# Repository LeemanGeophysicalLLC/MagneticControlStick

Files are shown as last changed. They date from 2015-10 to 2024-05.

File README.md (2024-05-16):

# Magnetic Control Stick

**THIS PRODUCT HAS BEEN RETIRED AND IS NO LONGER PRODUCED**

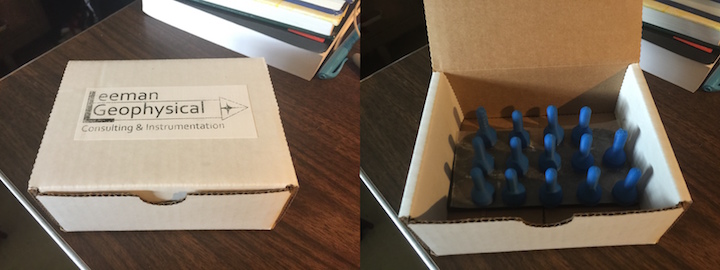
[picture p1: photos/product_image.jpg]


Magnet holder for controlling electronic devices. Designed for the
GeoPebble project at Penn State by John R. Leeman. Current design utilizes
0.5" x 0.125" rare earth magnets.

* We recommend super-glue or equivalent to ensure magnets stay in
the holders in all conditions.
* We have noticed that any extra gap in the space between the
bottom of the stick and the magnet surface can significantly decrease
performance. You can sand away extra plastic material after gluing magnets in
or reduce the gap in the OpenSCAD file.
* Printed on Taz4 by Lulzbot with no raft, skirt, or brim. Medium or fast
speed with ABS plastic. 40% infill.

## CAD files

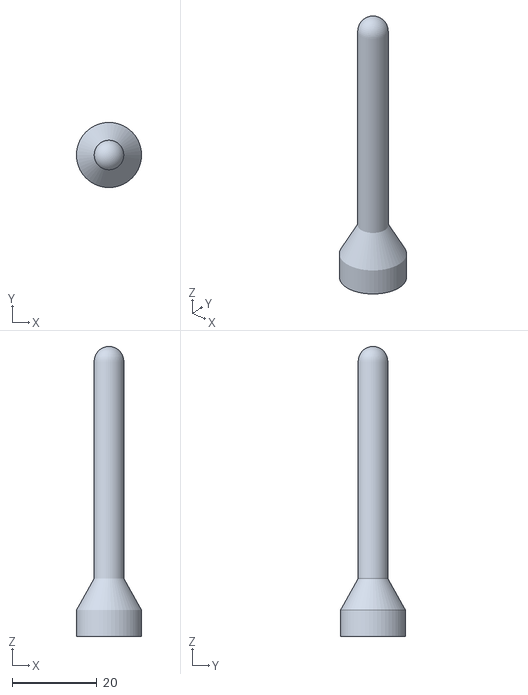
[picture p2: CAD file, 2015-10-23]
stl_files/Magnetic_Control_Stick_Tall.stl
15.4 x 15.4 x 68.5

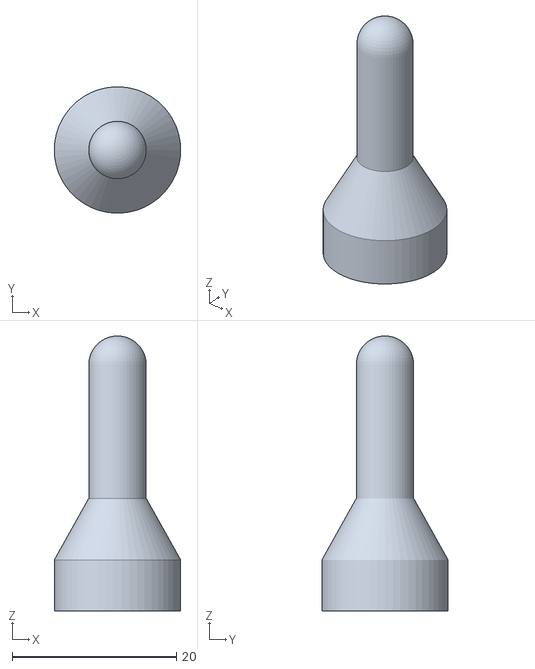
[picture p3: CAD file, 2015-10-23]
stl_files/Magnetic_Control_Stick_Short.stl
15.4 x 15.4 x 33.5

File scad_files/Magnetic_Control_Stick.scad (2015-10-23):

// Resolution
$fn=50;

// Paramters of the stick
stick_diameter = 7; // Handle Diameter (nominal 7 mm)
height = 30; // Total Height (nominal 30 mm or 65 mm)
wall_thickness = 2; // Thickness of sides/top of magnet area (nominal 2 mm)
recess_depth = 1; // Recess depth of magnet in bottom (nominal 0-1 mm)
taper_height = 7.5; // How tall the taper is (nominal 7.5 mm)

// Magnet Holes (actual + fudge factor)
magnet_radius = 6.35 + 0.35;
magnet_depth = 3.175 + 0.05;

// Calculated parameters
stick_radius = stick_diameter/2.;
stick_height = height - magnet_depth - wall_thickness - recess_depth;

base_width = (magnet_radius*2) + wall_thickness;
base_radius = base_width/2.;

union(){

    // Make the base of the stand with holes for the magnet
    difference(){
        // Base
        cylinder(magnet_depth + wall_thickness + recess_depth,base_radius,base_radius);
        // Make hole for magnet
        cylinder(magnet_depth + wall_thickness, magnet_radius,magnet_radius);
    }
 
    // Make the stick and round topper
    union(){
        // Make the narrow stick
        translate([0,0,magnet_depth + wall_thickness + recess_depth]) cylinder(stick_height,stick_radius,stick_radius);
        // Add the Topper
        translate([0,0,magnet_depth + wall_thickness + recess_depth + stick_height]) sphere(stick_radius);
    }
    
    // Make the strain relief at the base
    translate([0,0,magnet_depth + wall_thickness + recess_depth]) cylinder(taper_height, base_radius, stick_radius);
}

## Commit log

2015-10-23 Add tall and short versions of the STL
    [Magnetic_Control_Stick.stl, Magnetic_Control_Stick_Short.stl, Magnetic_Control_Stick_Tall.stl]
2015-10-23 Structure and add photo
    [Magnetic_Control_Stick.scad, Magnetic_Control_Stick_Short.stl, Magnetic_Control_Stick_Tall.stl]
2015-10-23 Add printing conditions
